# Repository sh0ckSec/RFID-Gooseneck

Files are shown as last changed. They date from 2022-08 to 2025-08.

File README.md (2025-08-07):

# RFID Gooseneck

Traditional RFID badge cloning methods require you to be within 3 feet of your target, so how can you conduct a socially distanced physical penetration test and clone a badge if you must stay at least 6 feet from a person? Since 2020, companies have increasingly adopted a hybrid work environment, allowing employees to partially work remotely, which has decreased the amount of foot traffic in and out of a building at any given time. After throwing around some ideas, I thought, why not create a mobile long-range reader device that we could deploy early in the morning at a client site and let it do all the work for us.  This project guide contains an entry-level hardware design that you can build in a day and deploy in the field in order to increase your chances of remotely cloning an RFID badge. 

 

This is part of an original full paper and talk given during **DEFCON 30** in the Physical Bypass Village **Keeping Your Distance: Pwning RFID Physical Access Controls From 6FT and Beyond** by myself and Twitter: @_badcharacters (https://www.youtube.com/watch?v=OLLaXOcuYfw). Each year (DEFCON 31, 32 and 33), the content is reiterated and improved upon, staying up on the latest techniques and gadgets to use in the field. The goal is to conduct a physical pen test without the need for a laptop, only a mobile phone and implant devices!

The content has been updated for **DEFCON 33** titled: **Flipping Locks: Remote Badge Cloning with the Flipper Zero and More**. In this tutorial, you'll learn how to clone the badge loot from your RFID Gooseneck reader quickly and easily!



#### NOTE: iCLASS SE/SEOS Downgrade Attack and Legacy Attack Methods are updated in the latest slide deck from DEF CON 33 (2025) - download the .pdf to review the attack methods.

 *Disclaimer:* **This guide is for educational and ethical hacking purposes ONLY. All penetration testing activities must be authorized by all relevant parties.**

### Here's the full build guide for making your own RFID Goosneck Long Range Reader! 

# Gooseneck Base Installation Guide 
Ok, let's do this. 

### Wooden Base BOM:
* MDF or Plywood (16"x16"x0.5")
* Non-Slip Furniture Feet: https://a.co/d/8oR8tHj  
* Pedestal Pro 36"H Gooseneck: https://bit.ly/3bCz6go
* 3/8" x 1 1/4" Carriage Bolts and Wing Nuts and Washers (Quantity of 6 each) 
* Black Spray Paint

### Step 1 - Cut Out Wood Base
* If you have access to a laser cutter or a ShopBot, feel free to download the "GooseneckBaseMK2Template_sh0ck" template file(s) or cut out your own 16"x16" piece of MDF or plywood. 



### Step 2 - Align Pedestal
* Center the gooseneck pedestal and place the edge of the base approximately 1.25" away from the edge of the base. The 1.25" (3.175cm) distance from the edge will counter-balance the weight of the long-range reader so it will not tip over when installed. 
* Next trace and drill the 3/8" mounting holes.



### Step 3 - Paint
* Spray the base with a matte black color of your choice.


### Step 4 - Install Feet 
* When the paint is dry, drill the non-slip furniture feet onto the bottom of the base. 




### Step 5 - Fasten Pedestal to Base 
Last, fasten the pedestal to the wooden base with bolts and wingnuts. Then place the pedestal cover over the top to conceal the screws. 




# Long Range Reader Cloning Guide
Let's build the long-range reader cloning device. 
### Long Range Reader BOM: 
* ESP RFID Tool: https://hackerwarehouse.com/product/esp-rfid-tool/
* Low-Frequency Long Range Reader (e.g., HID MaxiProx 5375) OR High-Frequency Long Range Reader (e.g., HID iCLASS SE R90) 
* Breadboard Jumper Wires - 3.9in (10cm): https://a.co/d/fja090p or 22AWG Wire: https://a.co/d/h7bbBom 
* 18AWG 12V 5A DC Power Pigtail Barrel Plug Connector Cable: https://a.co/d/7l56UFQ
* 12V 6000mAh/5V 12000mAh DC Battery: https://a.co/d/9czvggQ
* 3M Dual Lock Clear Velcro: https://a.co/d/gg4SzBd

### Wiring Guide 
Below is an example of the wiring guide to connect to a long-range reader with screw-in terminals using the ESP RFID Tool. Use the color-coded male-to-male breadboard wires to connect the two terminal interfaces between the Wiegand system and the ESP RFID Tool, as seen below.



* Then connect the 12V 5A DC Power Pigtail Barrel Plug Male Connector cable into the Wiegand system (HID iClass SE R90 pictured) and trail the cable to the outside of the reader so you can plug it into the 12V 6000mAh DC Battery. 



The same wiring applies to the low-frequency HID MaxiProx 5375 reader. 



Close-up of HID MaxiProx 5375 Wiring:



*WARNING:* Ensure when you are working with the HID MaxiProx 5375 that you change the jumper on the Shunt Pins settings from 2 and 3 +21-2.85 VDC (Default) TO Shunt Pins 1 and 2 +11.6-20.9VDC) because we are using a 12V battery. If you do not switch the jumper, you will fry the unit! YOU'VE BEEN WARNED! Double-check this for any reader you are working with, just in case. 



To remain as stealthy as possible, it is advised to turn off the audible "beep" if the reader allows you to. In this case, we can silence the beep on the HID MaxiProx 5375 reader by pushing down dipswitch #4 of SW1 (the farthest right of the switch sets). 



*Image Source: http://exfil.co/2017/01/17/wiegotcha-rfid-thief/*

*Note: For various configurations, check out the official ESP RFID Tool wiring guide here: https://github.com/rfidtool/ESP-RFID-Tool/blob/master/Installation-Schematics/README.md*

### ALTERNATIVE Raspberry Pi Setup: 
If you would like an alternative Raspberry Pi cloning device setup, I **HIGHLY RECOMMEND** checking out Mike Kelly's (Twitter @lixmk) Wiegotcha – RFID Thief guide: 
http://exfil.co/2017/01/17/wiegotcha-rfid-thief/ 

# Battery Mounting
Once you have wired everything, take 3M Dual Lock Velcro and affix it to the back of the battery and the back of the reader. This will ensure the battery will stay firm throughout the engagement and it looks like it is part of the unit. 

HID MaxiProx 5375



HID R90 



HID R90 


          
# Mounting Reader to Pedestal
Depending on the reader, you must find the correct mounting hole guide for each. You will have to manually drill holes into the back of the reader in order to center it to the gooseneck pedestal with carriage bolts and nuts. Below is an example mount guide for the HID iCLASS R90.



iCLASS SE Mounting and User Guide: https://fccid.io/JQ6-ICLASSU90/User-Manual/User-Manual-2360366 

HID iClass R90 Gooseneck finished look: 



# Flipper Zero - Cloning Low-Frequency Cards 
To remain incognito while at the client site, cloning a card with a mobile phone and a Flipper Zero hidden away will keep the lowest profile rather than fiddling with a laptop when you need to copy the card data. 

### Mobile Cloning Gear:
* Mobile Phone (Android or iOS)
* Flipper Zero: https://shop.flipperzero.one/
* Flipper Mobile App: https://docs.flipper.net/mobile-app 
* RFID T5557 Rewritable Cards: https://a.co/d/0NF2zJG



### Step 1  - Access RFID Loot
Once the implant is in place and a few employees have walked past the gooseneck reader, hop onto your phone and log into your RFID ESP Key SSID to look for loot. The default SSID is "ESP-RFID-Tool" but it is recommended to change the name to something that will blend into the target environment. In order to change the SSID and password to protect the ESP RFID Tool wifi (and not leak all your client's credentials to the world), jump over to the configuration page to customize the settings and change all your default passwords. 
* Default SSID: **ESP-RFID-Tool**
* URL: http://192.168.1.1

Default credentials to access the configuration page:
* Username: *admin*
* Password: *rfidtool*

(Full ESP RFID Tool user guide here: https://github.com/rfidtool/ESP-RFID-Tool)

Once you're on the ESP RFID Tool WiFi, access Data in the "List Exfiltrated Data" Page:


#### Note: Binary Code Breakdown 
It's not as crazy as you think, here's the breakdown of what the binary code means below:

Source:  https://accessgrid.com/guides/access-control-protocols/examples-of-every-access-control-bit-format 

### Step 2 - Copy the 2nd half of the Binary Payload and Convert to HEX
The "HEX" in the loot file was designed for a Proxmark 3 device. The Flipper Zero takes a different type of hex code so here's how you get your payload to clone your card. 



Copy the second half of the binary data: 
* 00010000100000101001110011 
  
REMOVE the leading and trailing parity bits:
* 001000010000010100111001

Copy this and convert it into HEX using a Bin-HEX Converter on your phone and poof! You have the 6 digit hex code for your Flipper!
* 001000010000010100111001 = 21 05 39

### Step 3 - Save your Card Data to the Flipper Zero

On your Flipper, **hit the center button** and navigate to > **125 hHz RFID** > **Add Manually**


Then **Select HID H10301** > Enter the Data: **210539**


Select **Save** > **Name the card** (Enter the desired name)


Select your saved card > **Info** (in order to look for your FC (Facility Code) and Card Number)


### Step 4- Clone your Card!
Select your saved card > **Write** it to a blank T5557 card


In a few seconds...


Boom! Happy Hunting! 
<p float="left">
          
          
DC32

 

</p>

# OLD METHOD - Cloning Low-Frequency Cards - Android Phone + Proxmark3 Easy 
**For the sake of documentation, I will leave the old method on this page. But finding the exact firmware for the Proxmark3 Easy can be tricky now, as the AndProx App is unsupported - it is highly recommended to use the Flipper Zero in the field for the easiest approach.**

To remain incognito while at the client site, cloning a card via an Android phone will keep the lowest profile rather than fiddling with a laptop when you need to copy the card data. 



### Mobile Cloning Gear:
* Android Phone or Tablet of your choice
* AndProx Android App: https://github.com/AndProx/AndProx  
* Proxmark3 Easy (available on eBay or AliExpress)
* USB OTG Cable - Type C To Micro: https://a.co/d/4HGdBqh
* RFID T5557 Rewritable Cards: https://a.co/d/0NF2zJG
* 3D Printed Case (optional): https://www.thingiverse.com/thing:3123482 
                                                                                                                 
MobileSetup
                                                                                                          

### Step 1A  - Access RFID Loot
Once the implant is in place and a few employees have walked past the gooseneck reader, hop onto your phone and log into your RFID ESP Key SSID to look for loot. The default SSID is "ESP-RFID-Tool" but it is recommended to change the name to something that will blend into the target environment. In order to change the SSID and password to protect the ESP RFID Tool wifi (and not leak all your client's credentials to the world), jump over to the configuration page to customize the settings and change all your default passwords. 
* Default SSID: **ESP-RFID-Tool**
* URL: http://192.168.1.1

Default credentials to access the configuration page:
* Username: *admin*
* Password: *rfidtool*

(Full ESP RFID Tool user guide here: https://github.com/rfidtool/ESP-RFID-Tool)

Once you're on the ESP RFID Tool WiFi, access HEX Code Data in the "List Exfiltrated Data" Page:



### Step 1B - Copy the HEX Code Payload!



### Step 2 - Android Cloning Setup
* Download and install AndProx (Root NOT required!): https://github.com/AndProx/AndProx 
* Plug in your Proxmark3 via OTG cable
* Click Connect Via USB
* Begin sending commands!

### Step 3 - AndProx Commands 
Once your Proxmark3 Easy is connected, copy your Hex Code and enter these commands: 



> lf hid clone [INSERT HEX CODE]

#Example: 
> lf hid clone 20043C0A73 

Verify your card data:
> lf search



Boom! Happy Hunting!

D3FC0N 

Special Shoutouts to the Bill Graydon, Terry, Karen and the team of the Physical Security Village and Zero_Chaos of the Radio Frequency Village for hosting us at DEFCON!

<a href="https://www.buymeacoffee.com/sh0cksec" target="_blank">Buy Me A Coffee</a>

# References

* Bunsen, Auston. "Examples of every access control bit format." February 2025, https://accessgrid.com/guides/access-control-protocols/examples-of-every-access-control-bit-format 
* Farrell, Michael and Boris Hajduk. "AndProx." July 2021, GitHub, https://github.com/AndProx/AndProx
* Harding, Cory. "ESP-RFID-Tool." March 2018, GitHub, https://github.com/rfidtool/ESP-RFID-Tool
* Hughes, Nathan. "Flipper Maker" May 2022, https://flippermaker.github.io  
* Kelly, Mike. "Wiegotcha – RFID Thief." January 2017, https://exfil.co/2017/01/17/wiegotcha-rfid-thief/ 
* Phrack. “Flipper Zero RFID Thief” https://www.phrack.me/hardware/2025/02/26/Flipper-Zero-RFIDThief.html 
* Rumble, Rich. "RFID Sniffing Under Your Nose and in Your Face." DerbyCon IX, September 2019, https://www.youtube.com/watch?v=y37j6RDtybQ
* W., Viktor. "Enclosure For Proxmark3 Easy." Thingiverse, September 2018, https://www.thingiverse.com/thing:3123482
* White, Brent and Tim Roberts. "Breaking Into Your Building: A Hacker's Guide to Unauthorized Access." NolaCon 2019, May 2019, https://www.youtube.com/watch?v=eft8PElmQZM

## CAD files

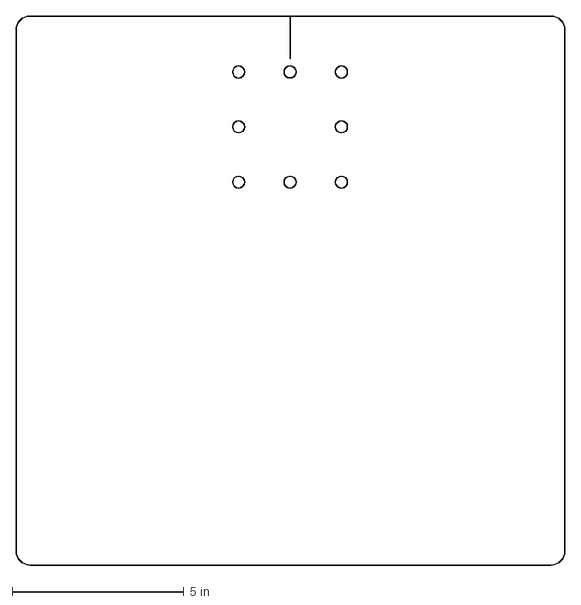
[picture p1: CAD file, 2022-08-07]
GooseneckBaseMK2Template_sh0ck.dxf
16.0 x 16.0 in

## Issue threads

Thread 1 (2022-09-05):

Range Problem

jsarkisian, 2022-09-05:
I have one of these built with the ESPKey, a Maxiprox 5375, and the battery pack you linked. While I do not have it built out as a gooseneck, I do have it in a mobile form hiding in a thin laptop bag. The best range I can get is about a foot. Perhaps there is more info in your video of your talk from DC30, but until then, how are you getting 6FT out of it?

This battery pack is 12V output, whereas the 10 AA / 1.5v output per battery power bank I had installed in my own version got to about 15v and had a bit better range. What am I missing?

Thanks!

sh0ckSec, 2022-09-07:
Hey! The goal is to deploy an implant near a building entrance and remote into it through wifi, therefore you're physically 6ft away from your target. The range remains the same for all hardware due to the limitations, so the trick is to use social engineering to trick a target into getting within range of your implant and have the implant do all the work for you! Check the official slides that I just uploaded to the repository for more context. Thanks!

jsarkisian, 2022-09-08:
Thanks!

fwiw… this bad boy gets you 2 full feet while mobile easy.. just tested:

Krisdonia 50000mAh Laptop Power Bank 5/9/12/16/19/20V Portable Laptop Battery Charger with QC3.0 USB-A Port & 12V Type-C Port for Laptop, Tablet, Smartphone and More Devices https://a.co/d/44CDc9d

subjec2change, 2025-08-09:
I'm able to get around 6 to 8 in just through one layer of a laptop bag and I believe it's because the ESP RFID modules Wi-Fi is causing interference because if I take it out of the loop and don't allow it to get power then I get dummy ranges at around 15 to 19 volts supplied to the 5575 reader. Should I wrap and the ESP in aluminum foil maybe?

Closed 2025-08-06.
